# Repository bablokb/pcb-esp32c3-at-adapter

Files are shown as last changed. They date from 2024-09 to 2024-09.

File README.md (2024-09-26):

Adapter-PCB for ESP32C3 SuperMini Running ESP-AT Firmware
=========================================================

This small breakout for the ESP32C3 SuperMini adds an Stemma/Qt
connector for the pins of UART1. This allows the ESP32C3 to be used as
a wifi co-processor. The other side of the Stemma/Qt must be connected
to power, ground and an UART of the host MCU. This could also be a
Stemma/Qt connector, if the respective pins of the host can also be
repurposed from I2C to UART.

Note: the VCC of the Stemma/Qt is connected to 3V3. The SuperMini is
usually happy with this direct 3V3 power-supply (this skips the
internal regulator).  As an alternative, change the jumper on the back
to 5V and feed 3.3-6V from the host MCU.  According to the datasheet
of the regulator, it does not deliver 3.3V with an input lower than
about 3.5V, but my tests show that the SuperMini is robust in this
respect.

The SuperMini can also be used in standalone mode. In this case, the Stemma/Qt
serves as an ordinary I2C connector.

See <https://github.com/bablokb/circuitpython-esp32at> for a software solution.

Ready to use production files for JLCPCB are in the directory `production_files/`.

Schematic
---------

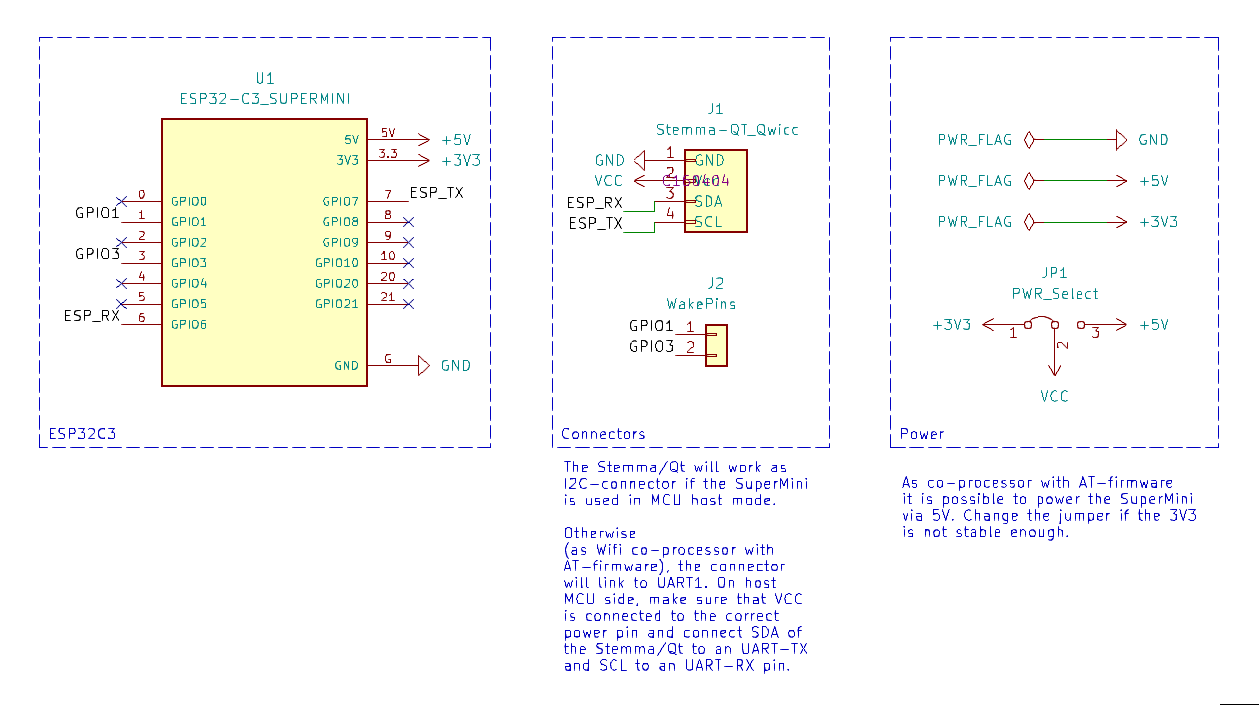
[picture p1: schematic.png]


Layout
------

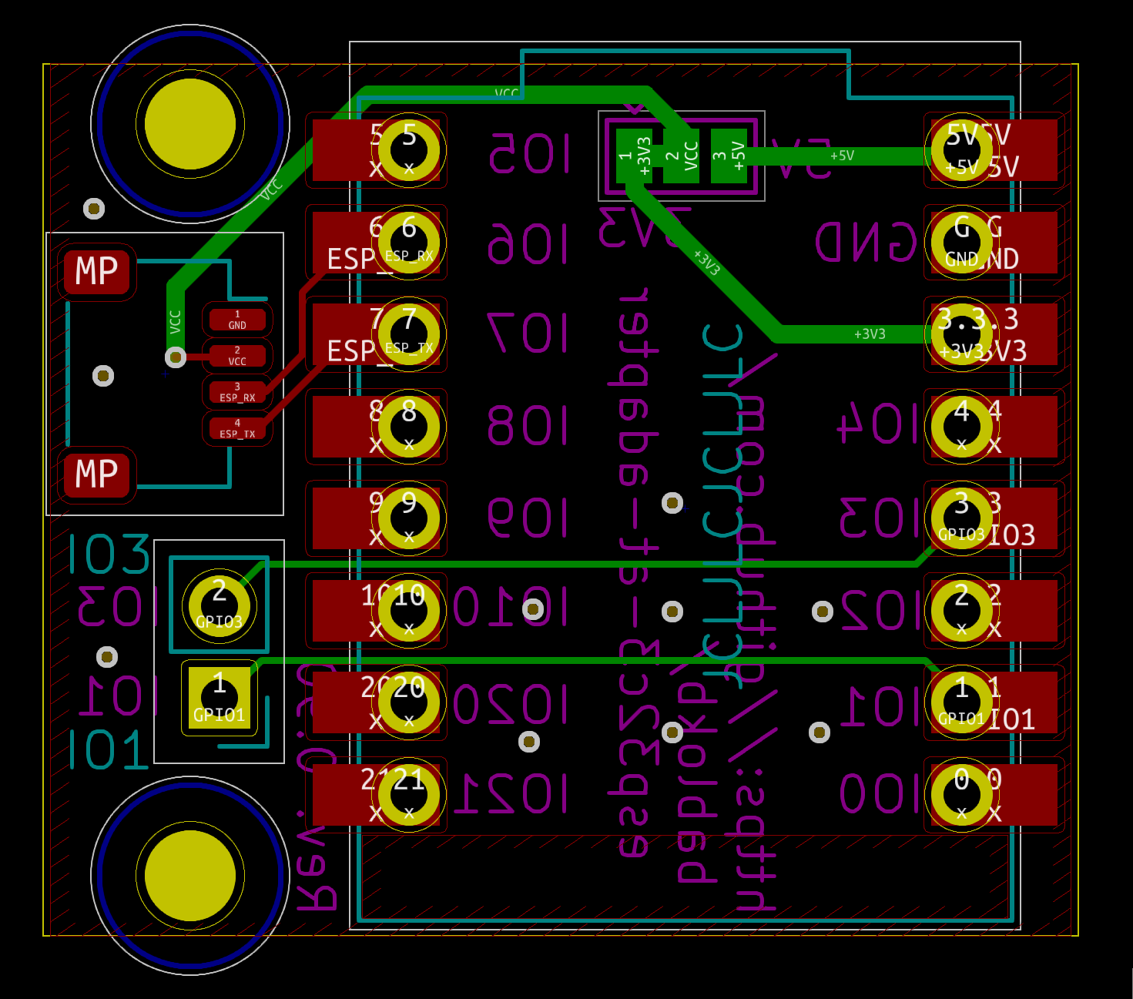
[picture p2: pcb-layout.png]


3D-Views
--------

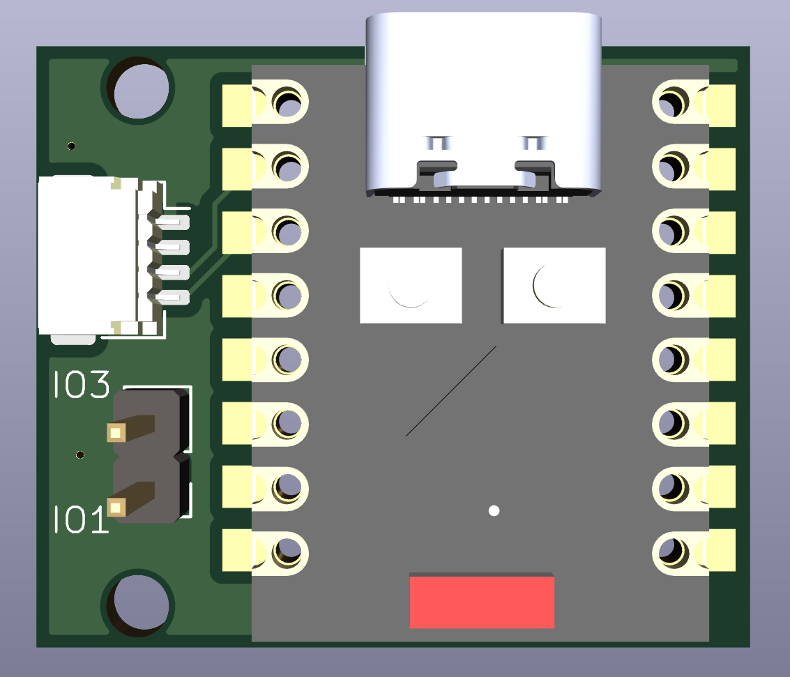
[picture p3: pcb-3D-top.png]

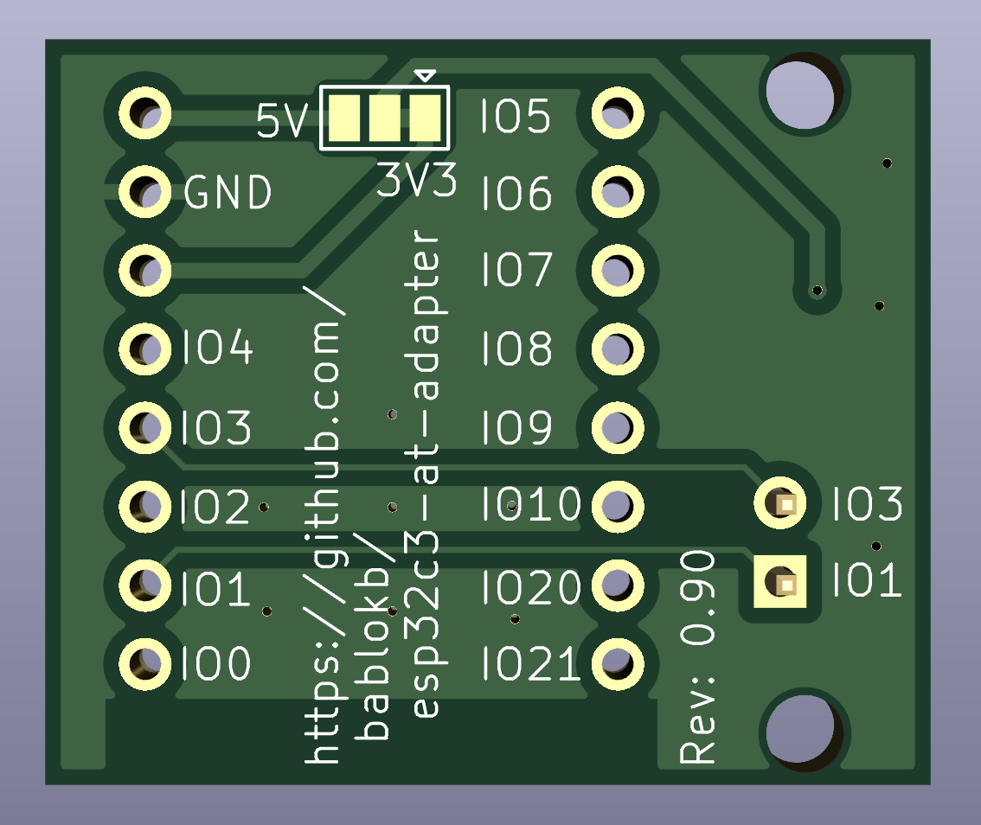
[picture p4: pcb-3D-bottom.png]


License
-------

[![CC BY-SA 4.0][cc-by-sa-shield]][cc-by-sa]

This work is licensed under a
[Creative Commons Attribution-ShareAlike 4.0 International
License][cc-by-sa].

[][cc-by-sa]

[cc-by-sa]: http://creativecommons.org/licenses/by-sa/4.0/
[cc-by-sa-image]: https://licensebuttons.net/l/by-sa/4.0/88x31.png
[cc-by-sa-shield]:
https://img.shields.io/badge/License-CC%20BY--SA%204.0-lightgrey.svg

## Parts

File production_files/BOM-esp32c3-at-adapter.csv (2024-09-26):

Comment | Designator | Footprint | LCSC
Stemma-QT_Qwicc | J1 | JST_SH_SM04B-SRSS-TB_1x04-1MP_P1.00mm_Horizontal | C160404

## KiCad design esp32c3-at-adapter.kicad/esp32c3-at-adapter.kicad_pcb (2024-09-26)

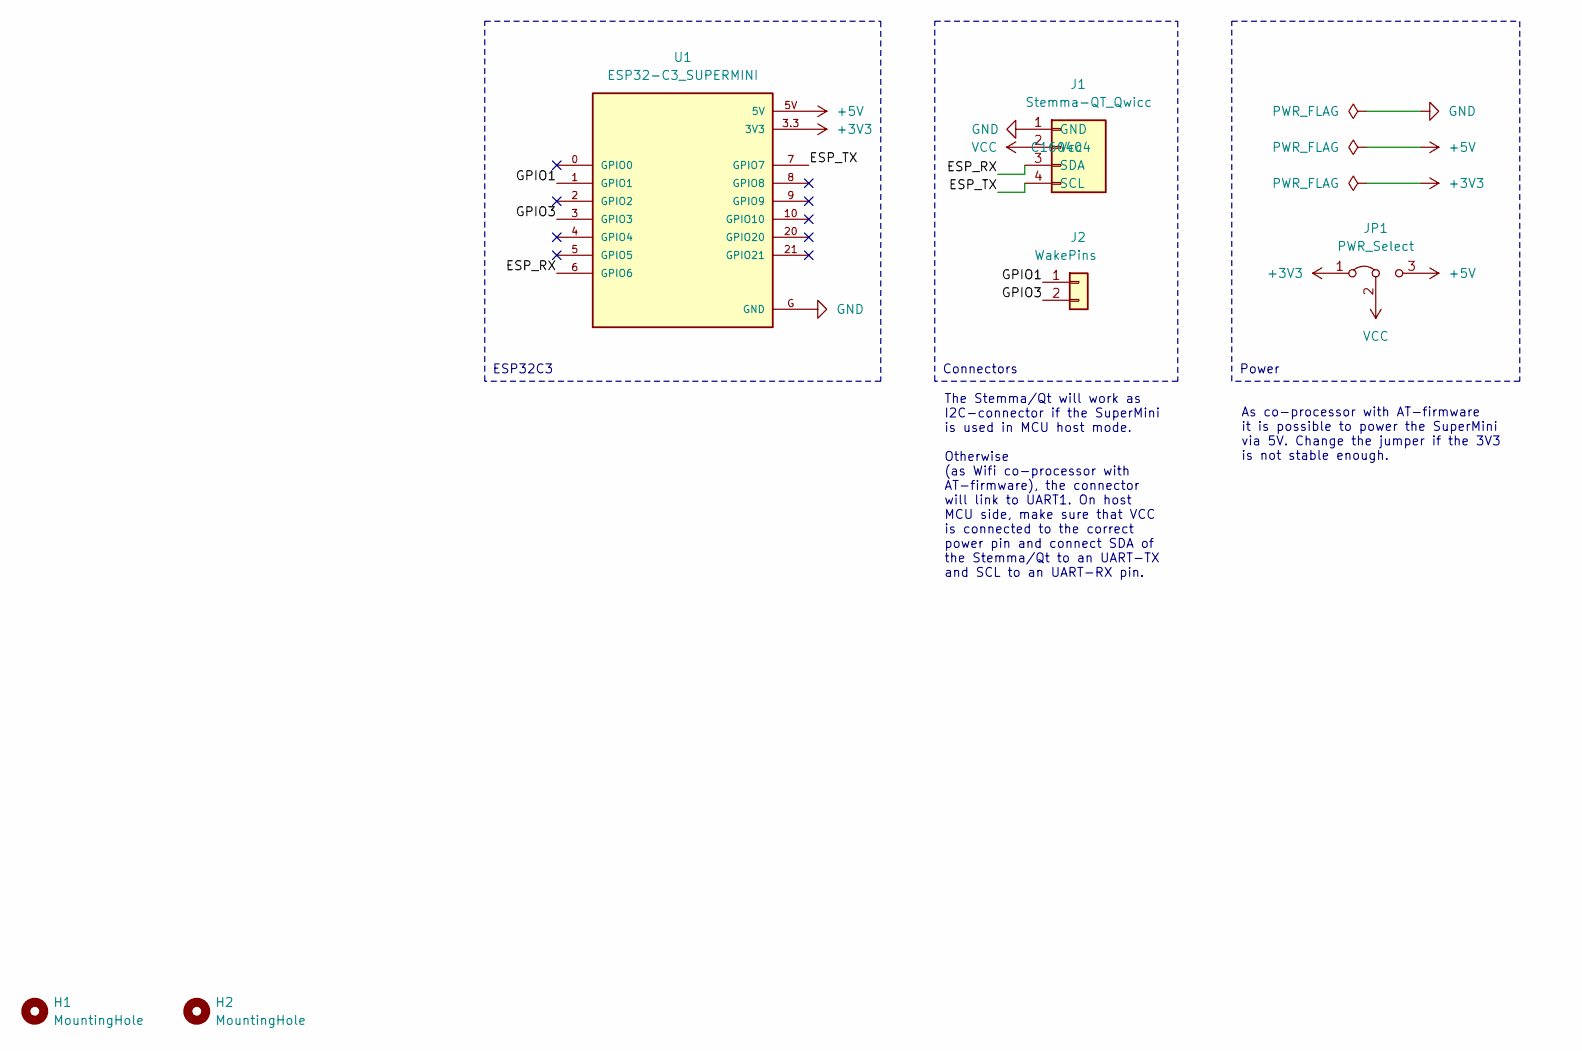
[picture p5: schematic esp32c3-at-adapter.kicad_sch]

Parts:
H1, H2: MountingHole; MountingHole_2.5mm
J1: Stemma-QT_Qwicc; JST_SH_SM04B-SRSS-TB_1x04-1MP_P1.00mm_Horizontal; LCSC C160404
J2: WakePins; PinHeader_1x02_P2.54mm_Vertical
JP1: PWR_Select; SolderJumper-3_P1.3mm_Bridged12_Pad1.0x1.5mm
U1: ESP32-C3_SUPERMINI

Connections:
+3V3: JP1.1 (A), U1.3.3 (3V3)
+5V: JP1.3 (B), U1.5V
/ESP_RX: J1.3 (SDA), U1.6 (GPIO6)
/ESP_TX: J1.4 (SCL), U1.7 (GPIO7)
/GPIO1: J2.1, U1.1 (GPIO1)
/GPIO3: J2.2, U1.3 (GPIO3)
GND: J1.1 (GND), U1.G (GND)
VCC: J1.2 (Vcc), JP1.2 (C)

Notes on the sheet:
Power
ESP32C3
Connectors
As co-processor with AT-firmware it is possible to power the SuperMini via 5V. Change the jumper if the 3V3 is not stable enough.
The Stemma/Qt will work as I2C-connector if the SuperMini is used in MCU host mode. Otherwise (as Wifi co-processor with AT-firmware), the connector will link to UART1. On host MCU side, make sure that VCC is connected to the correct power pin and connect SDA of the Stemma/Qt to an UART-TX and SCL 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

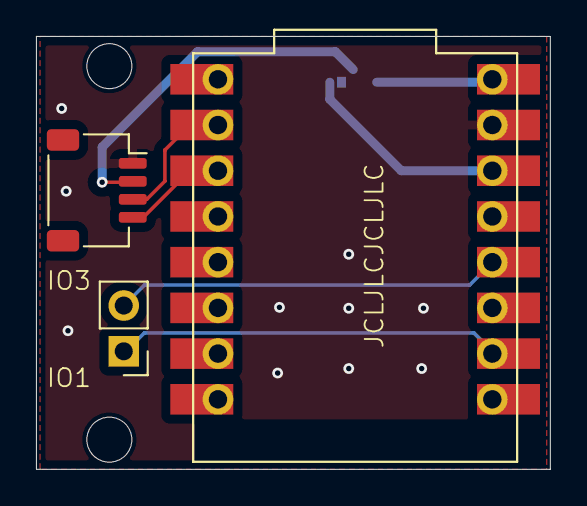
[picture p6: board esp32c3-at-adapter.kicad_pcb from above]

Board: 2 copper layers, 28.5 x 24.1 mm, 6 parts (1 on the bottom side), 8 nets.

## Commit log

2024-09-26 initial version
    [esp32c3-at-adapter.kicad_pcb, esp32c3-at-adapter.kicad_sch]
2024-09-26 Rev: 0.90 (first production test)
    [BOM-esp32c3-at-adapter.csv, esp32c3-at-adapter.kicad_pcb, esp32c3-at-adapter.kicad_sch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]
